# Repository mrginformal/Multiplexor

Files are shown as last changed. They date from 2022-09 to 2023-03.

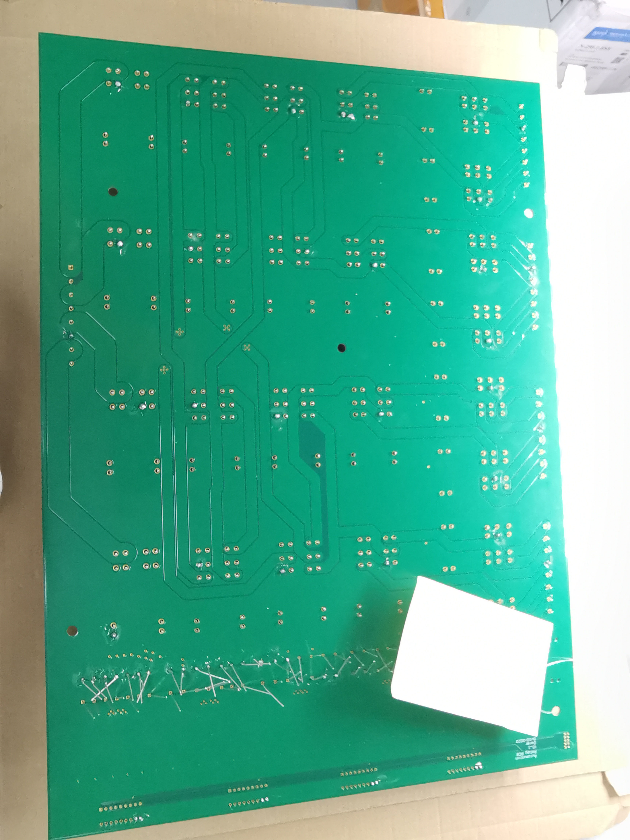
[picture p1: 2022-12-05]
Images/6.jpg

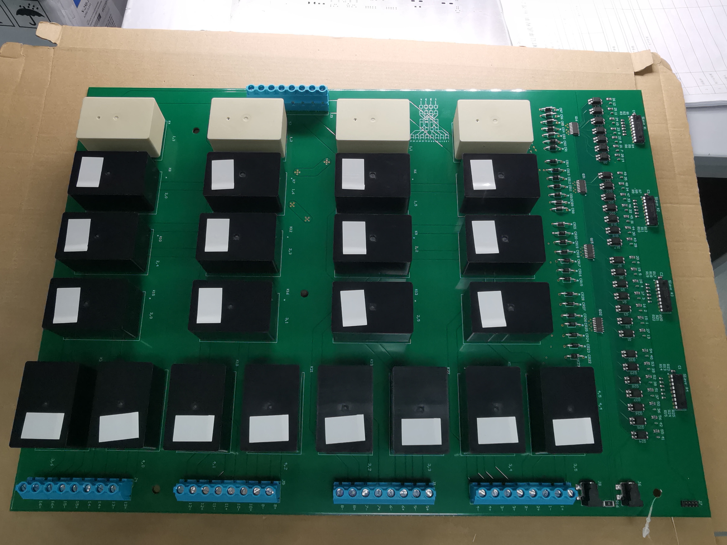
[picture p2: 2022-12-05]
Images/1.jpg

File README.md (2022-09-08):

# 4-IN 16-OUT Multiplexor

This repo contains datasheets, E-CAD and and the Controlling software of the Multiplexor device

The need:

In order for a devices to be tested against multiple use case devices and or lab instruments with out intervention in a single test setup, it is nessisary to have a way to replace the manual process of making the physical connections between the devices. By removing this step, much larger test sequences can be made by chaining together smaller sequences that would otherwise be seperated by manual connection changes. This devices serves to remove or greatly reduce the necessity of reconfiguration. This device is designed to be modular and be used in conjuction with other devices being developed. 

ex: Imagine 16 DC use case devices, connected to 4 yetis simultaneously which are toggled X number of times. Total connections = (#of yetis) X (# of devices) X (# of repeats). If X were 30 for statistical signifigance - that would be 1920 connections a technicial would have to make for just those 16 use cases devices. We currently have over 100 use case devices that are tested each regression. 

Description: 

This device is created such that 8 inputs can be directed to any of the 32 output lines and for the most part run simultaniously with some exceptions. Sets of DPDT relays make the connections and move the paths in pairs(either + - or Hot Neutral) effectively making the device 4 input pairs to any 16 output pairs. It is also worth noting that the terms input and output are loosly defined here and there is no reason one could not use the 16 outputs as inputs and vice versa. The device is rated up to 400V before its creepage requirments are invalidated(AC or DC)and up to 30A of Current. The necissary condition to ensure that the 4 inputs can be connected to the 16 outputs simultaniously is that the electrical paths for each input, output pair must not share a common bus at any point or in other words "cross". To see if paths "cross" refer to the control diagram in firware which shows how the relays create the paths. Typically it is possible for all inputs to be connected to the desired outputs at once and there is an internal check that will terminate the command before execution if a "cross" is detected.

An I2C bus connects to 4 slave devices which each have gpio pins. These pins are used to control the state of each relay. The identifier of the relay on the board and the path diagram is labeled as follows(controlling slave #, bit position of gpio register that controls it). The i2c address is adjustable via address select resistors with up to 8 unique  on each bus. The control software is in python and has preconfigured functions which simply allow the user to state which input --> output connects should be made as well as the duration the connection should last. The nessisary steps to disconnect the live signals, make the path changes, check for short circuits, and over all ensure the isolated pathways are delt with correctly is all handled automatically.

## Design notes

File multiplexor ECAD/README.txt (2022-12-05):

12/01/2022 -- A EMI issue was found where ESD on a nearby conductor could produce an EMI wave that would pull the reset pin on each i2c to GPIO low enough to
trigger Reset. To combate this a .1uf cap was added to each each reset pin to short high frequency signals(200khz was the emi packet)to ground.
A simple 1k resistor was also added between reset and the pi's ground to then bleed off those caps when no power is connected. Additionally the
the supply voltage has been bumped up to 5V from 3.3V. This appears to have fixed the issue.

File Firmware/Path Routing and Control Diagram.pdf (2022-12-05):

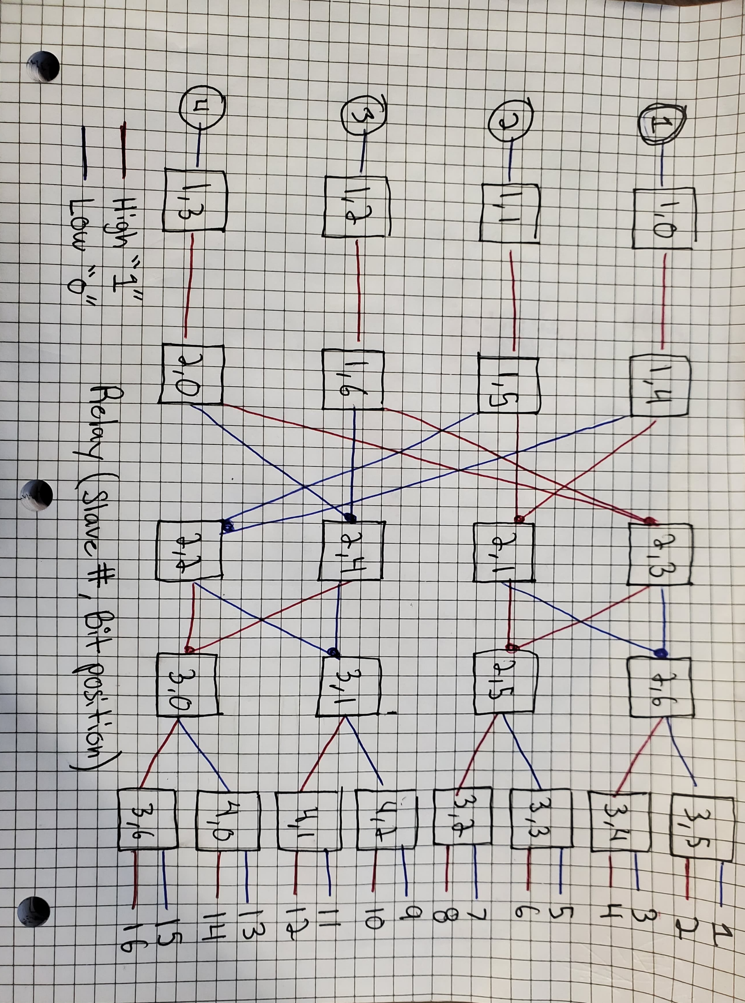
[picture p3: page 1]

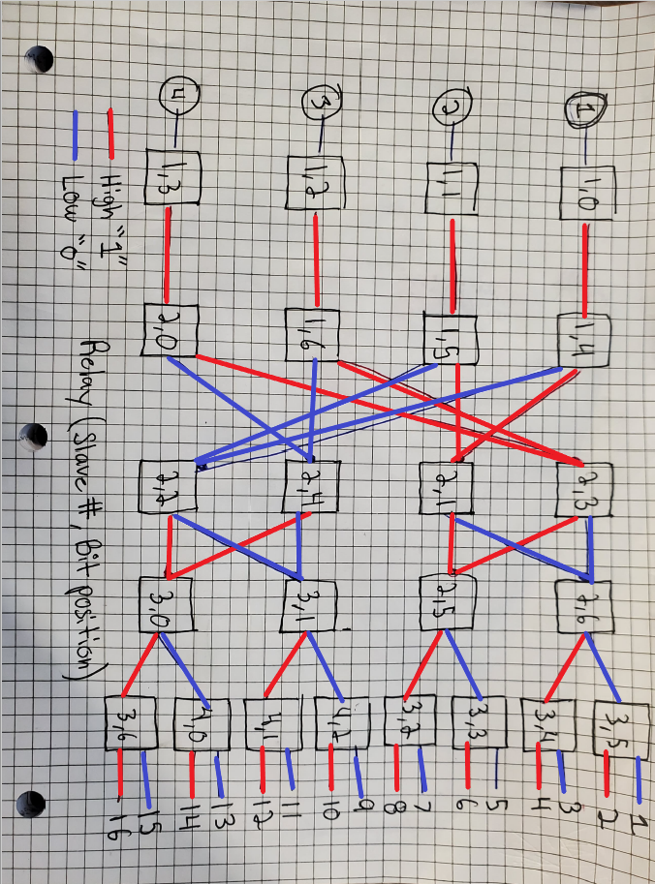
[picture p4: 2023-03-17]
Firmware/tempsnip.png

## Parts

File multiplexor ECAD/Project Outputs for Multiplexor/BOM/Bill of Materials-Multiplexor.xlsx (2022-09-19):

Comment | Description | Designator | Footprint | LibRef | Quantity | Manufacturer | Manufacturer 1
CL10A106MQ8NNNC | No Description Available | 1, 2, 3, 4, 5, 6, 7, 8, 9, 10, 11, 12, 13, 14, 29, 30, 31, 32, 33, 34, 35, 36, 37, 38, 39, 40, 41, 42 | CAP_CL10_SAM | CL10A106MQ8NNNC | 28
RMCF1206FT330R | No Description Available | 15, 16, 17, 18, 19, 20, 21, 22, 23, 24, 25, 26, 27, 28, 43, 44, 45, 46, 47, 48, 49, 50, 51, 52, 53, 54, 55, 56 | STA_RMCF1206_STP | RMCF1206FT330R | 28
GCM188R71H104KA57D | Cap 100nF, 50V, X7R, Ceramic, 1608(0603) | C1, C2, C3, C4 | CAPC1608N_NP | CAP_n100n_0603_50V | 4 | Murata Electronics North America
1N4007-G | No Description Available | CR1, CR2, CR3, CR4, CR5, CR6, CR7, CR8, CR9, CR10, CR11, CR12, CR13, CR14, CR15, CR16, CR17, CR18, CR19, CR20, CR21, CR22, CR23, CR24, CR25, CR26, CR27, CR28 | 1N4-G | 1N4007-G | 28
TB005-762-08BE |  | J1, J2, J3, J4, J5 | CUI_TB005-762-08BE | TB005-762-08BE | 5
PJ-002AH-SMT | 2.1mm x 5.5mm Barrel Jack 5A@24V 30mOhm Contact Resistance | J6, J8 | PJ-002AH-SMT | PJ-002AH-SMT | 2 | CUI Inc
 |  | J7 | 10pinheader | TMMH-105-01-F-D | 1
6-1423008-7 | General Purpose Relay DPST-NO (2 Form A) 24VDC Coil Through Hole | K1, K2, K3, K4 | RELAY_6-1423008-7 | 6-1423008-7 | 4
T92S11D12-24 | No Description Available | K5, K6, K7, K8, K9, K10, K11, K12, K13, K14, K15, K16, K17, K18, K19, K20, K21, K22, K23, K24 | T92S11D12-24_TEC-corrected | T92S11D12-24 | 20
FOD817DSD | OPTOISOLATOR 5KV TRANSISTOR 4SMD | Q1, Q2, Q3, Q4, Q5, Q6, Q7, Q8, Q9, Q10, Q11, Q12, Q13, Q14, Q17, Q18, Q19, Q20, Q21, Q22, Q23, Q24, Q25, Q26, Q27, Q28, Q29, Q30 | FP-709AH-MFG | CMP-2000-06281-2 | 28 | ON Semiconductor
MC1413BDR2G | No Description Available | Q15, Q16, Q31, Q32 | SOIC16_751B-05_ONS | MC1413BDR2G | 4
0603_k4.7K | RES 4.7K OHM 1/10W 1% 0603 SMD | R1, R2, R3, R4, R5, R6, R7, R8, R9, R10, R11, R12, R13, R14, R15, R17, R18, R19, R20, R21, R22, R23, R24, R25 | RESC1608N | 0603_k4.7K | 24 | Vishay Dale
CR2512-J/-000ELF | No Description Available | R16 | BO_CR2512 | CR2512-J/-000ELF | 1
MCP23008-E/P | No Description Available | Slave #1, Slave #2, Slave #3, Slave #4 | PDIP18_300MC_MCH | MCP23008-E/P | 4

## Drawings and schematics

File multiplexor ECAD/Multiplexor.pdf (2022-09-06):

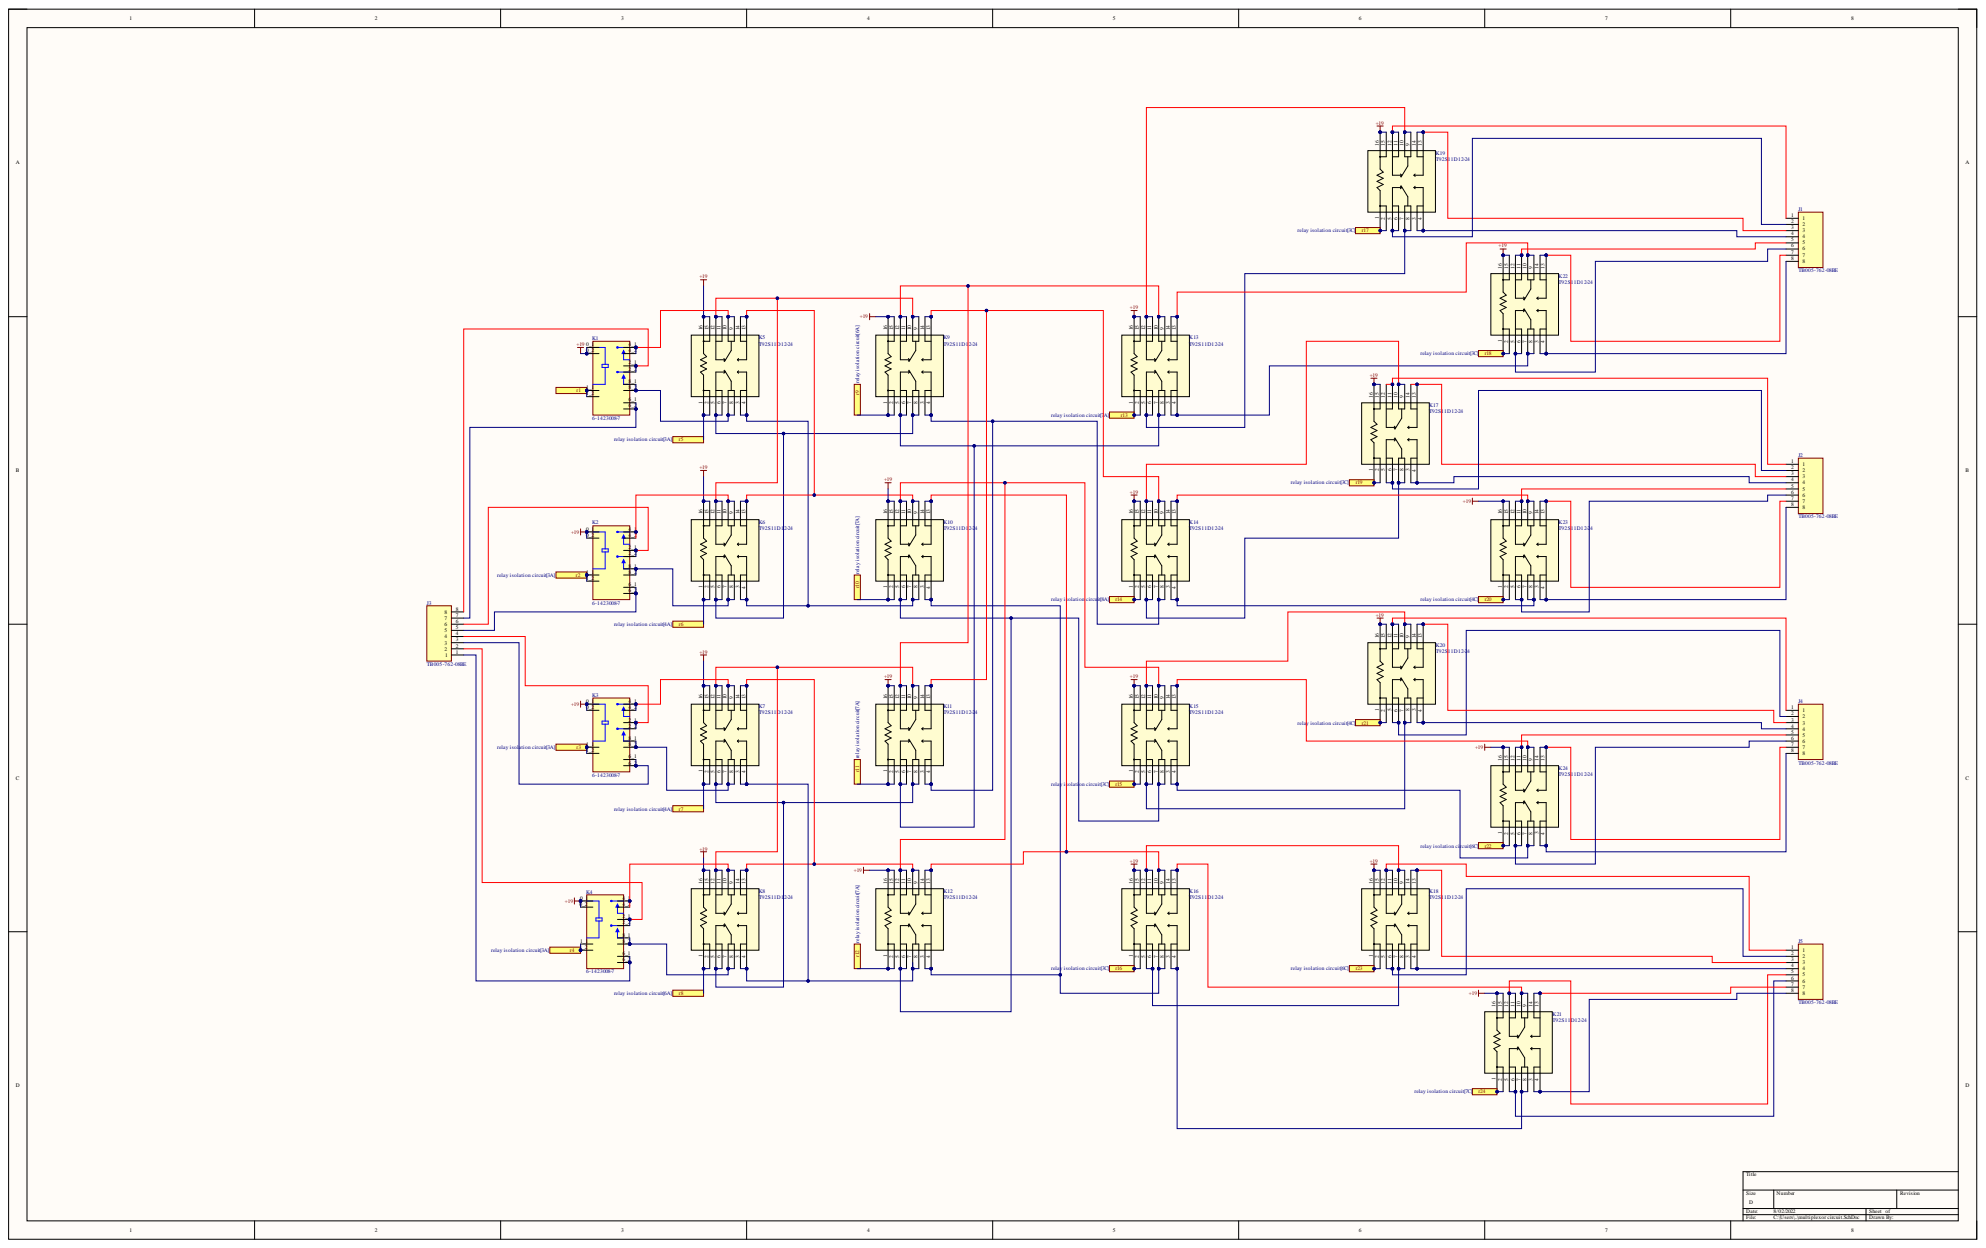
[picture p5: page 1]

r9 relay isolation circuit[6A] r10 relay isolation circuit[7A] r11 relay isolation circuit[7A] r12 relay isolation circuit[7A]

Size DDat | N umb er | Rev i s ion

e: 8 / 0 2 /2022 Fi l e: C: \U sers \ . . \mu l t i p lex or circu i t .SchD oc | Sheet o f Draw n By :

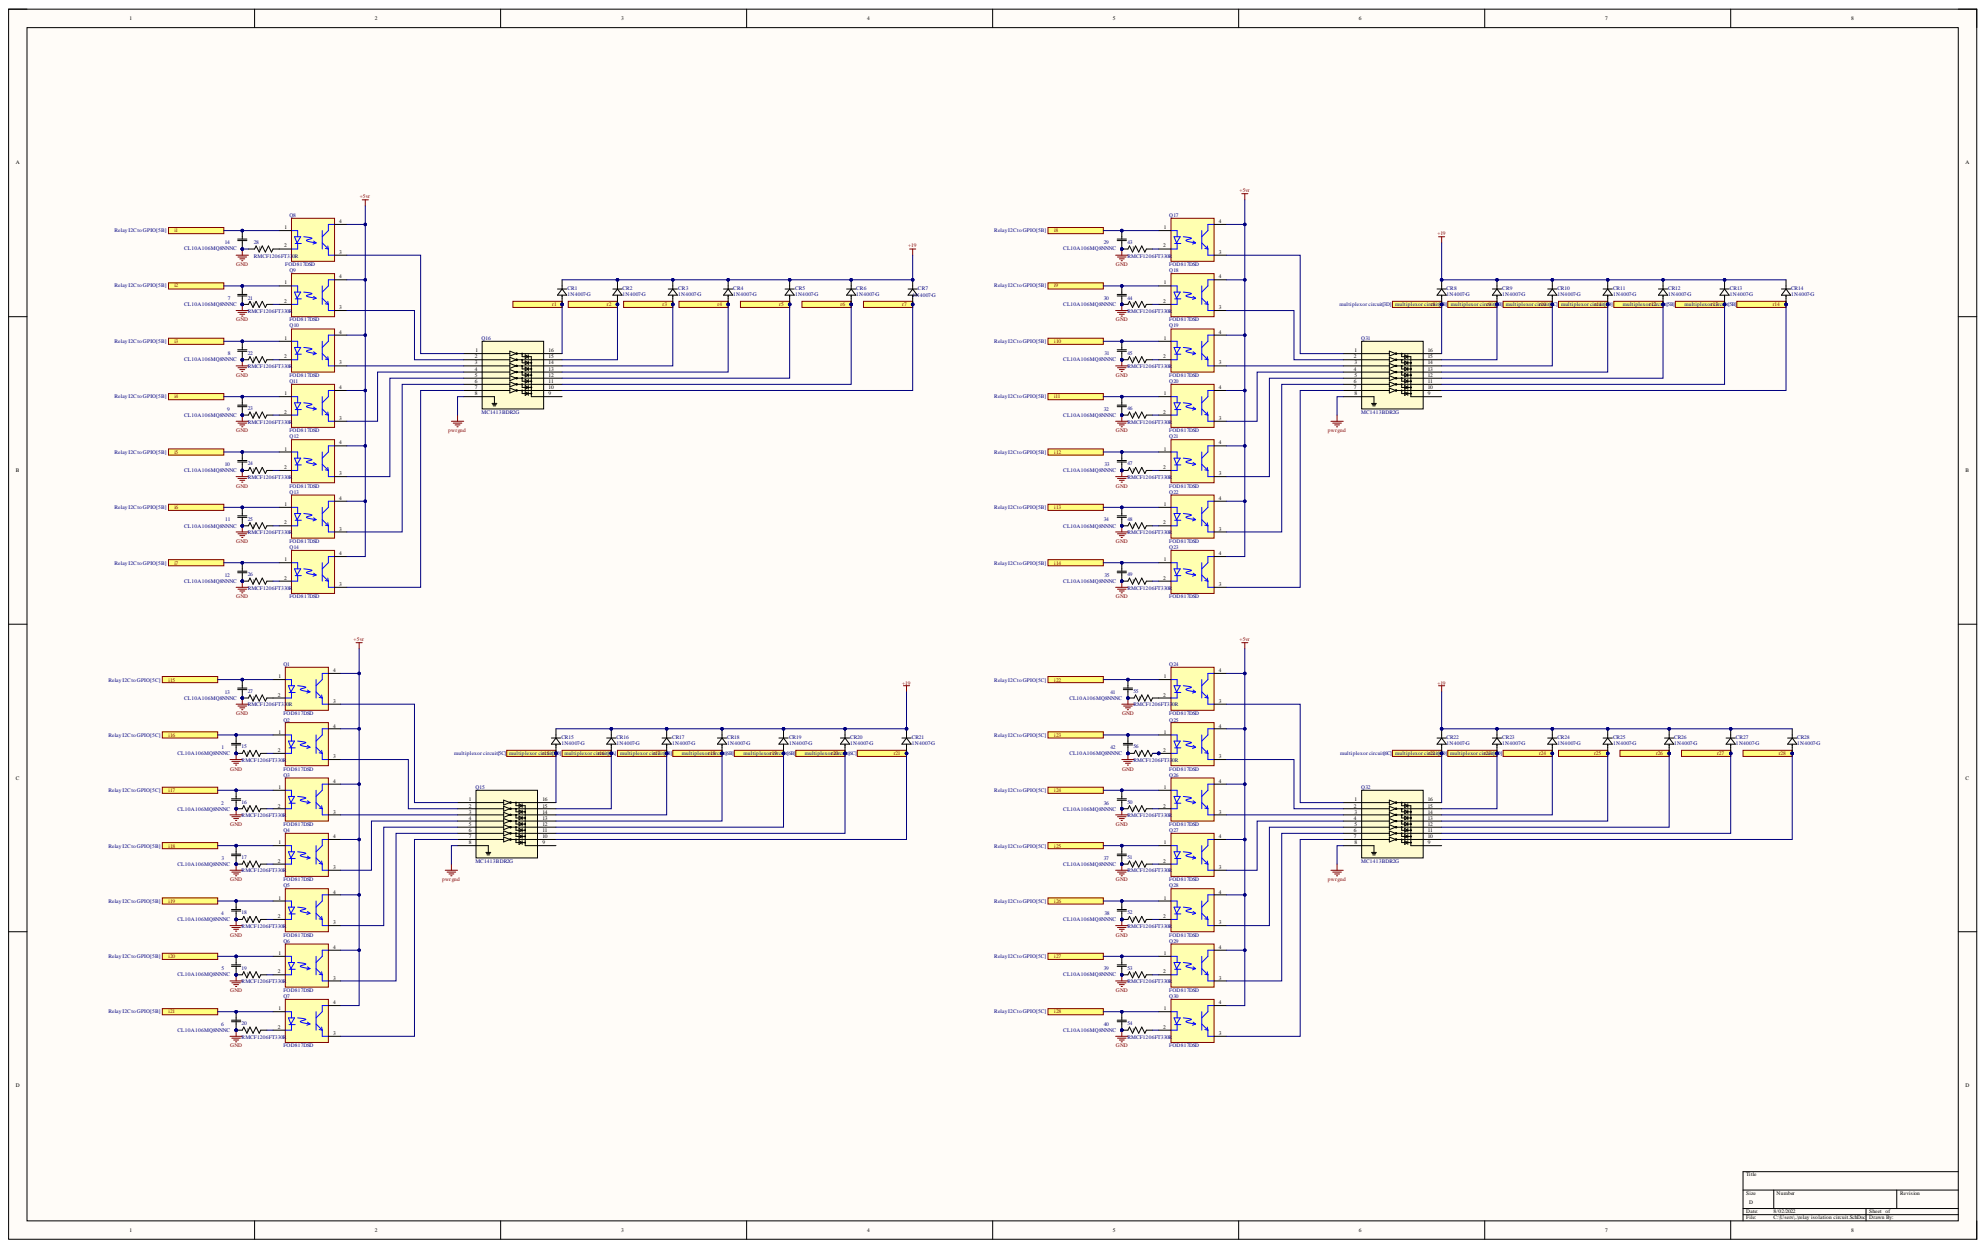
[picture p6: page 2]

3 4

Size D | Number | Revision

Date: 8/02/2022 File: C:\Users\..\relay isolation circuit.SchDoc | Sheet of Drawn By:

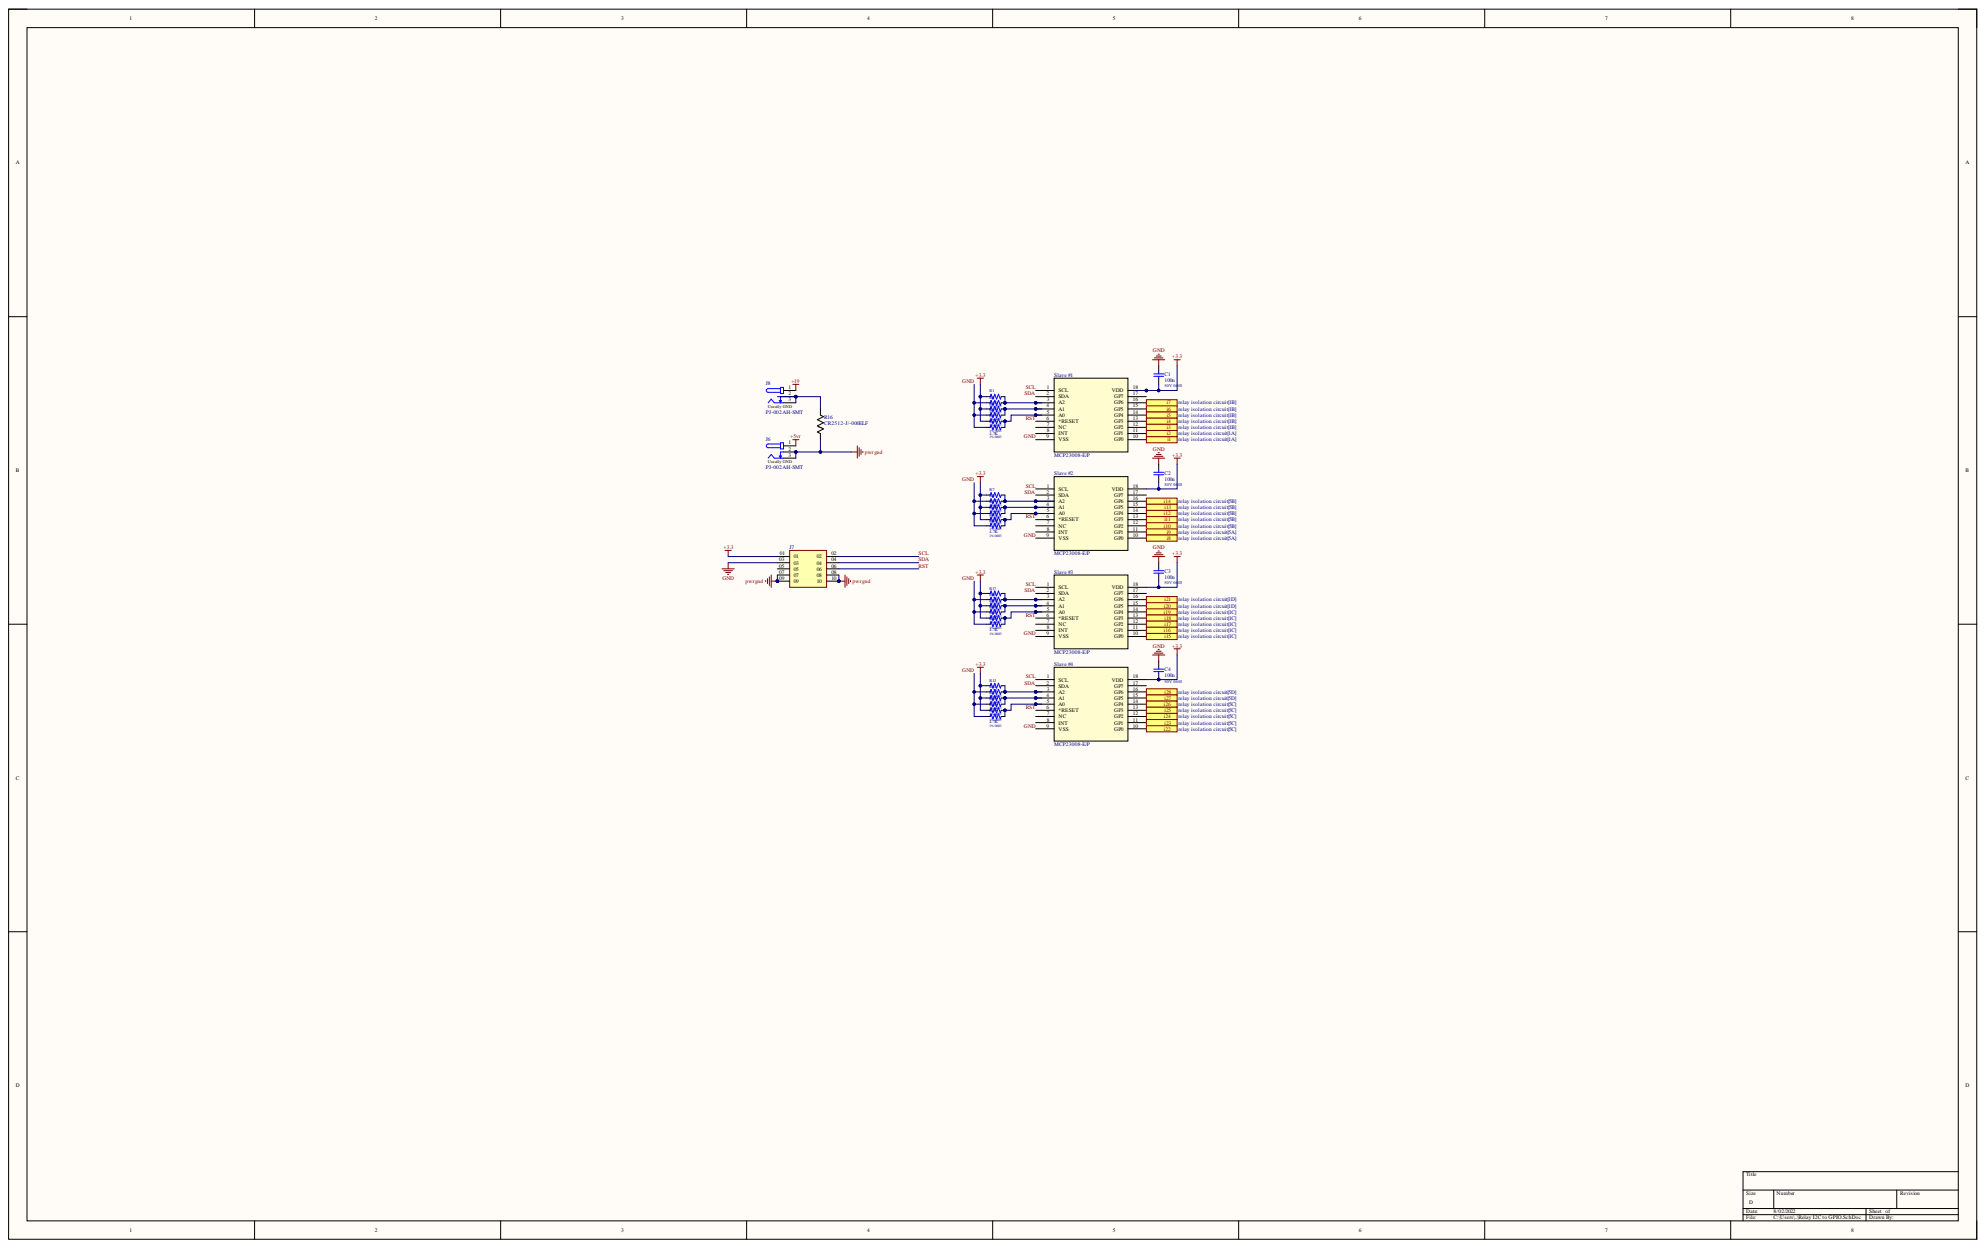
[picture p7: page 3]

Size DDat | N umb er | Rev i s ion

e: 8 / 0 2 /2022 Fi l e: C: \U sers \ . . \Relay I2C t o GPIO .Sch D o c | Sheet o f Draw n By :

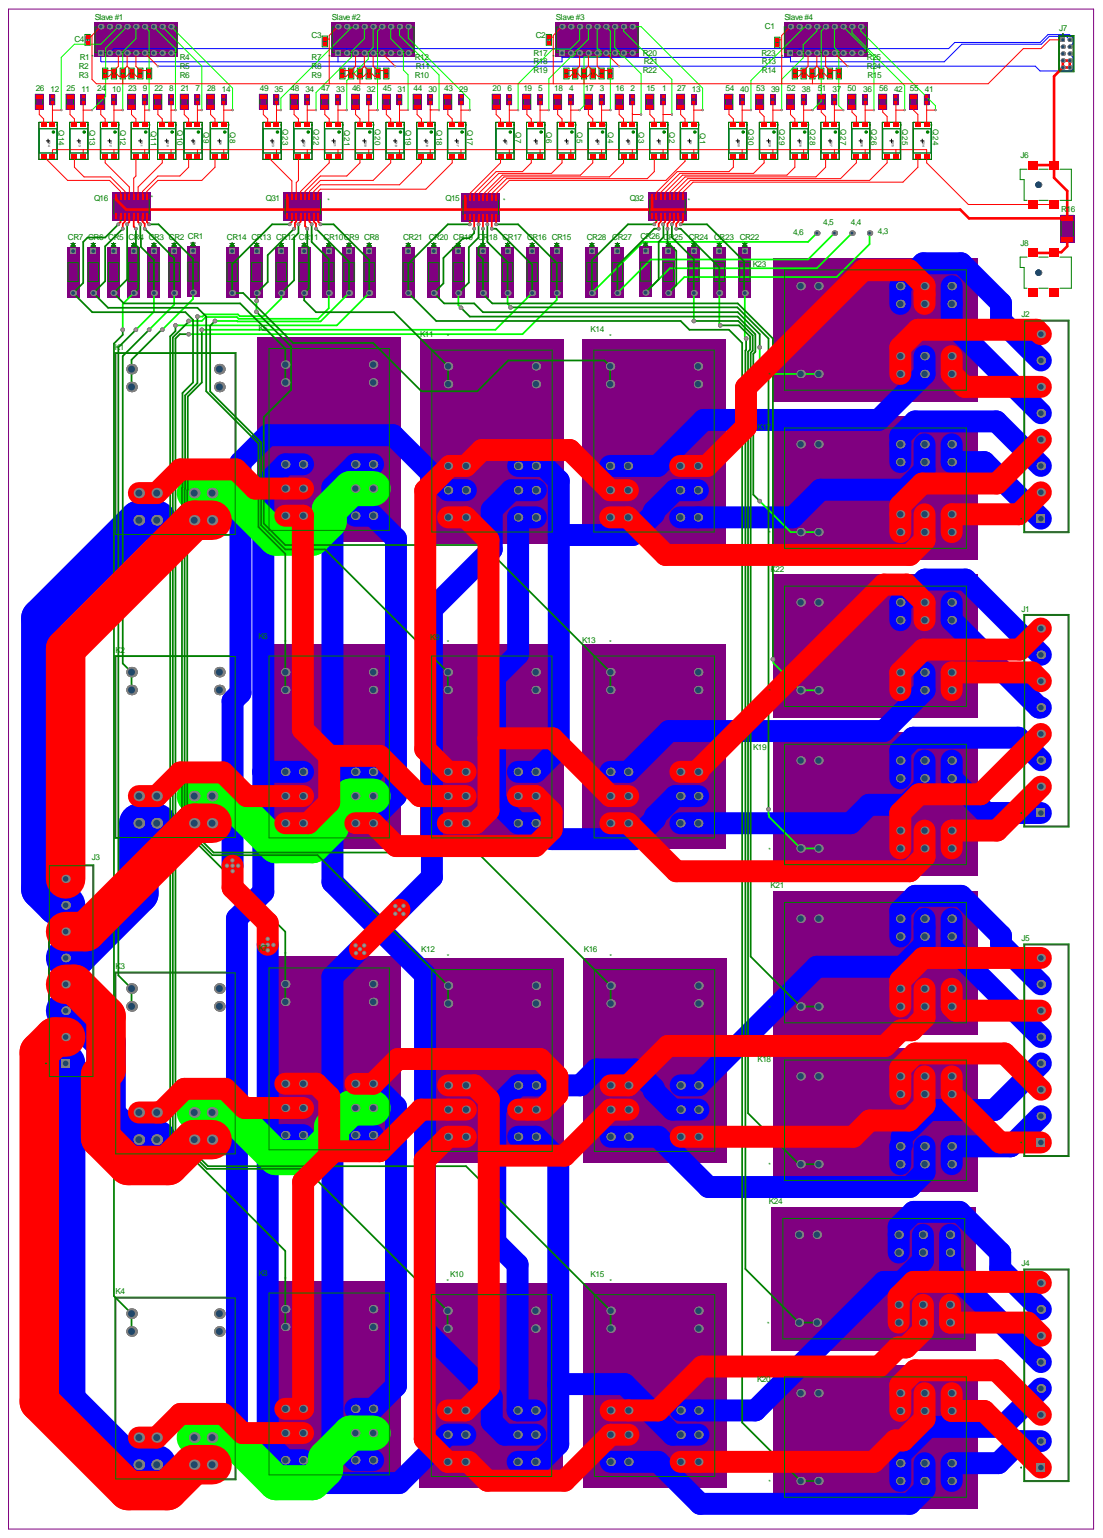
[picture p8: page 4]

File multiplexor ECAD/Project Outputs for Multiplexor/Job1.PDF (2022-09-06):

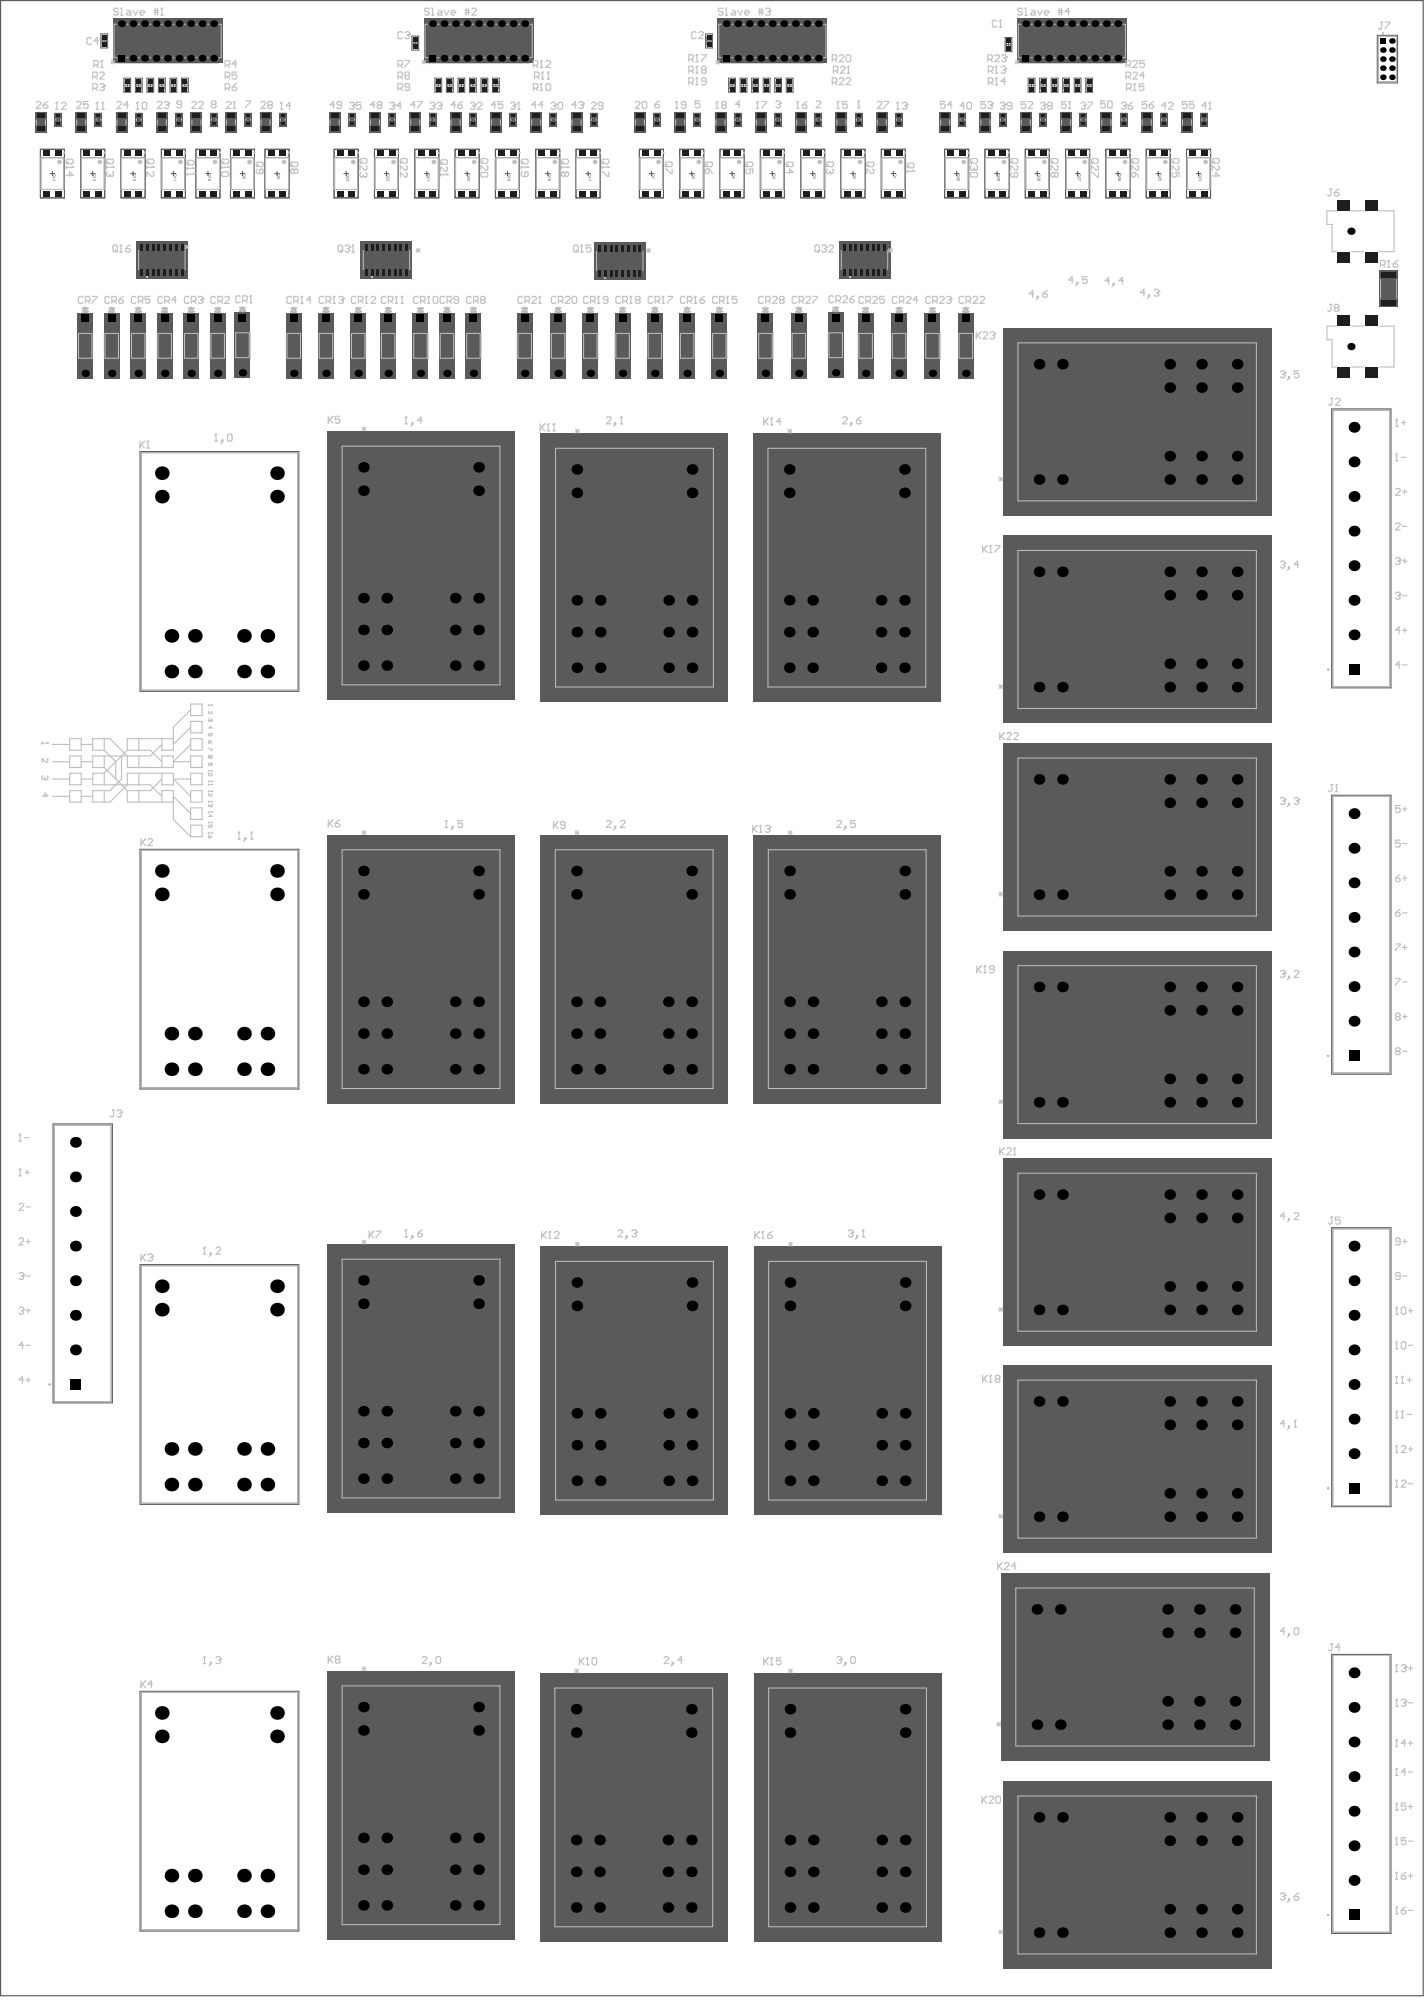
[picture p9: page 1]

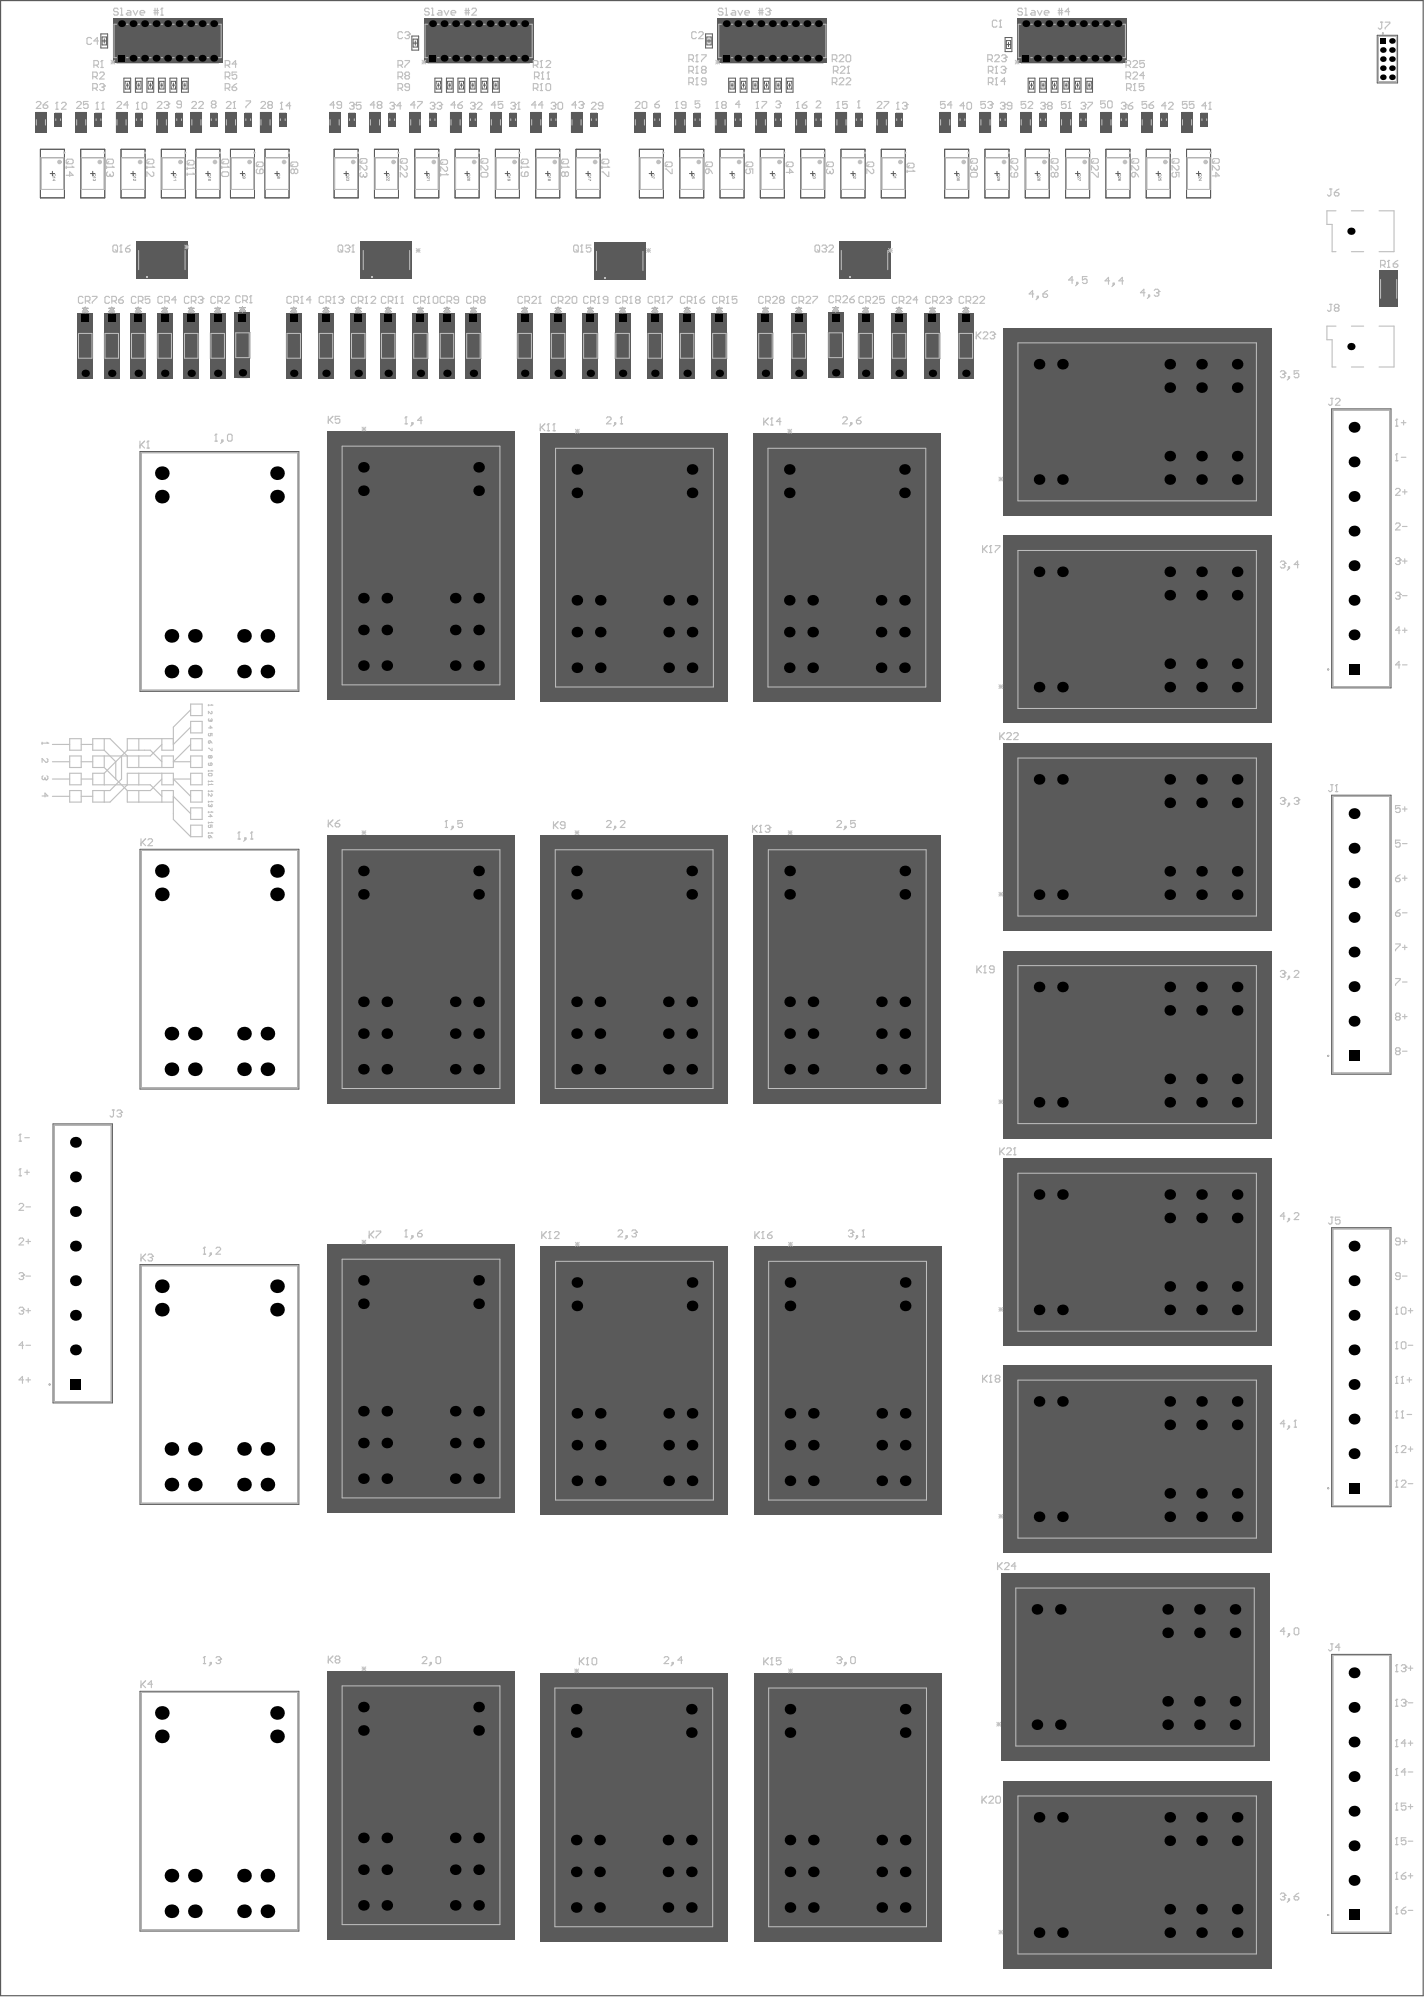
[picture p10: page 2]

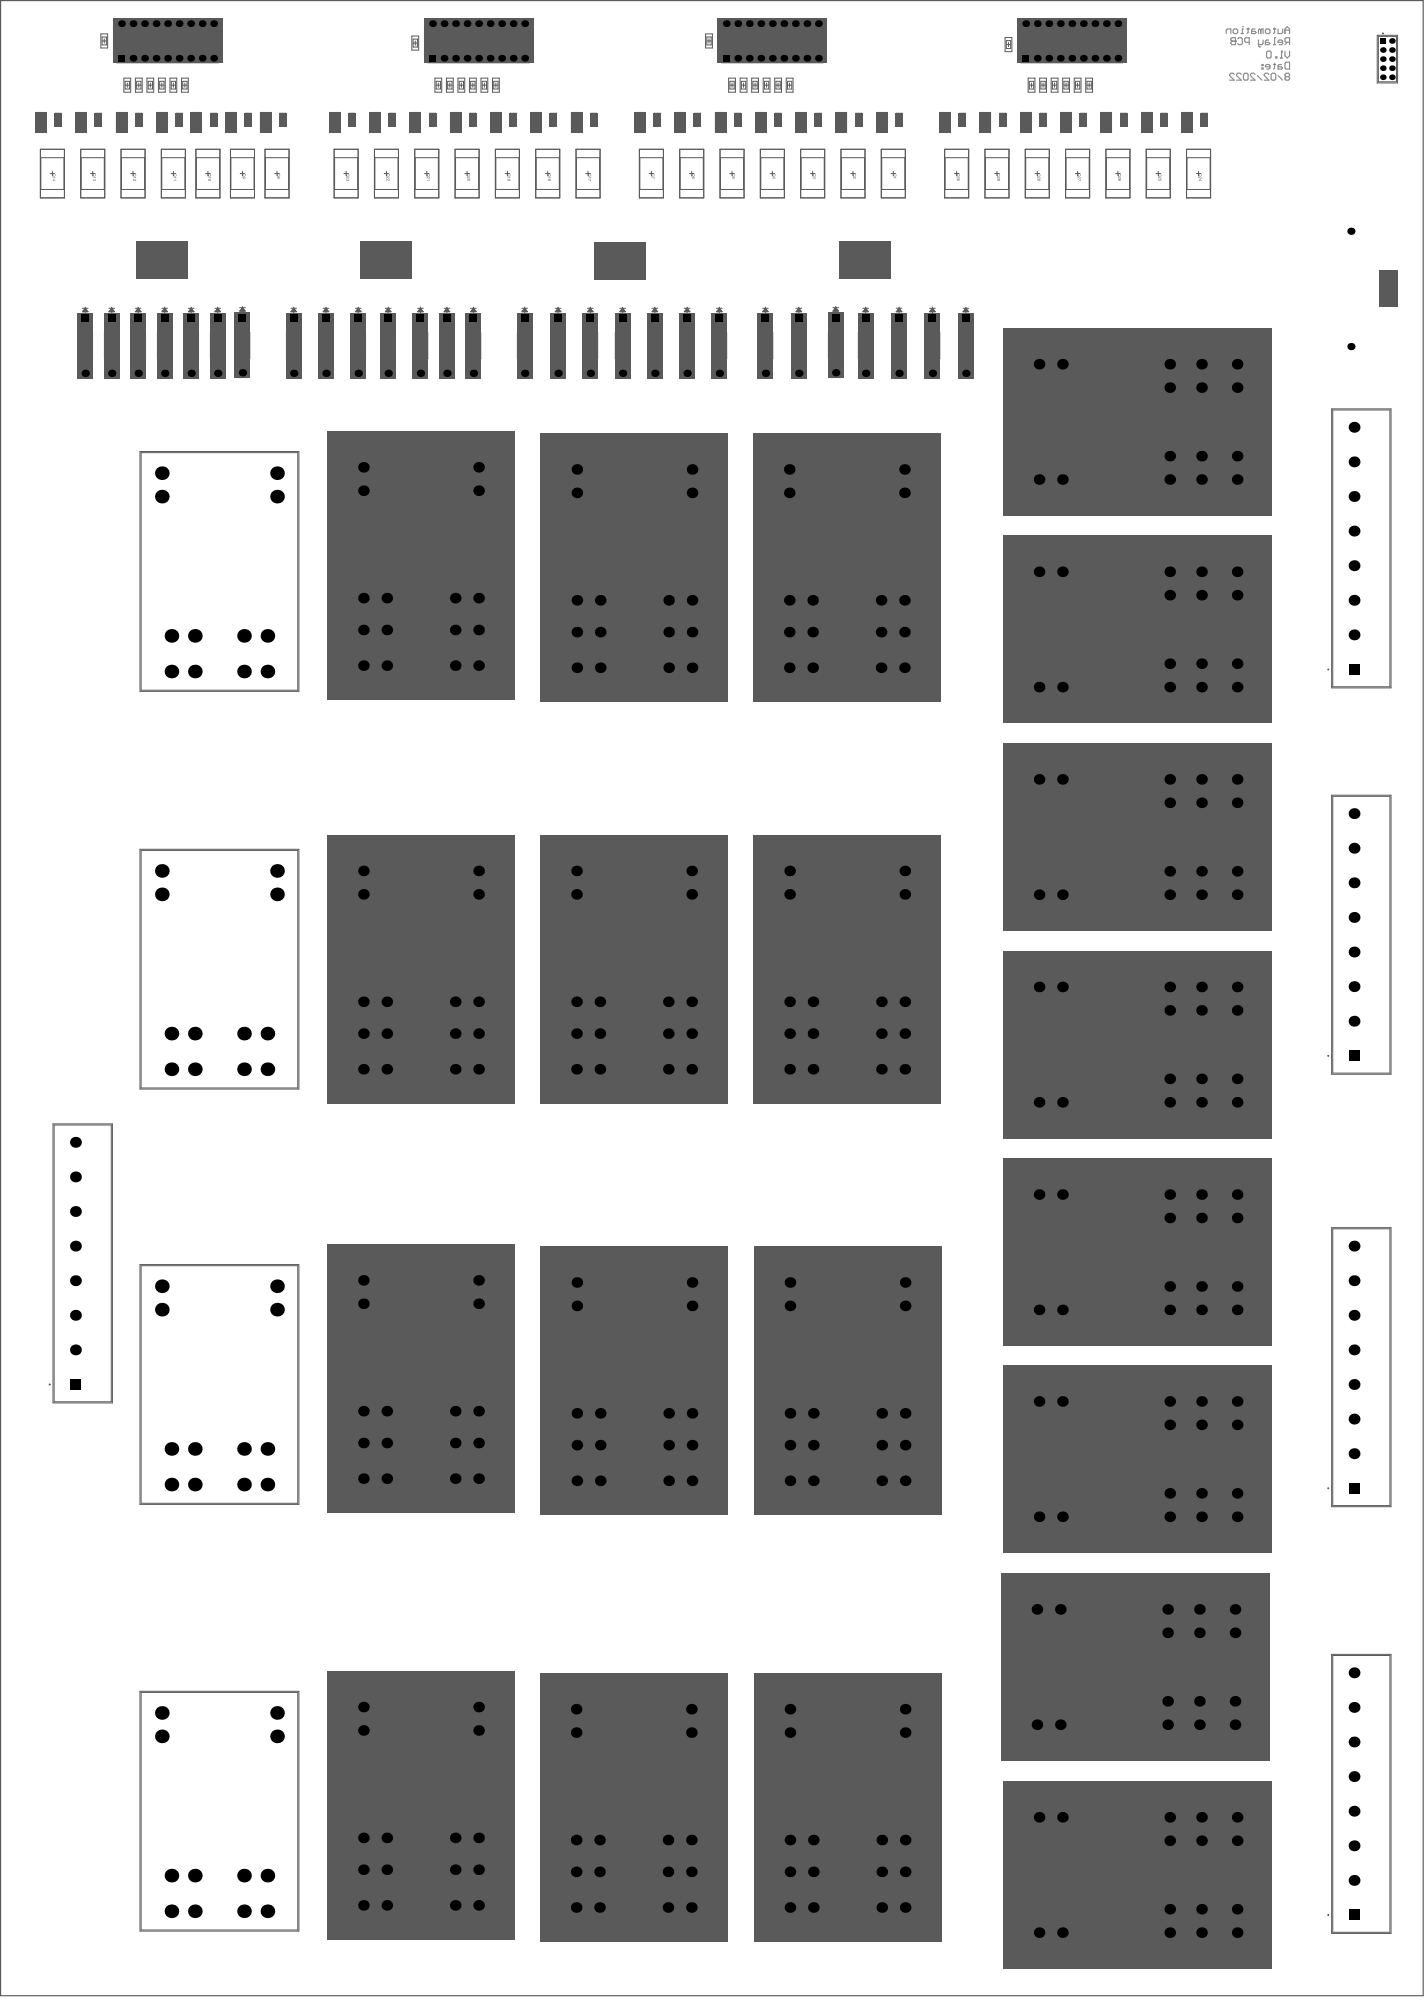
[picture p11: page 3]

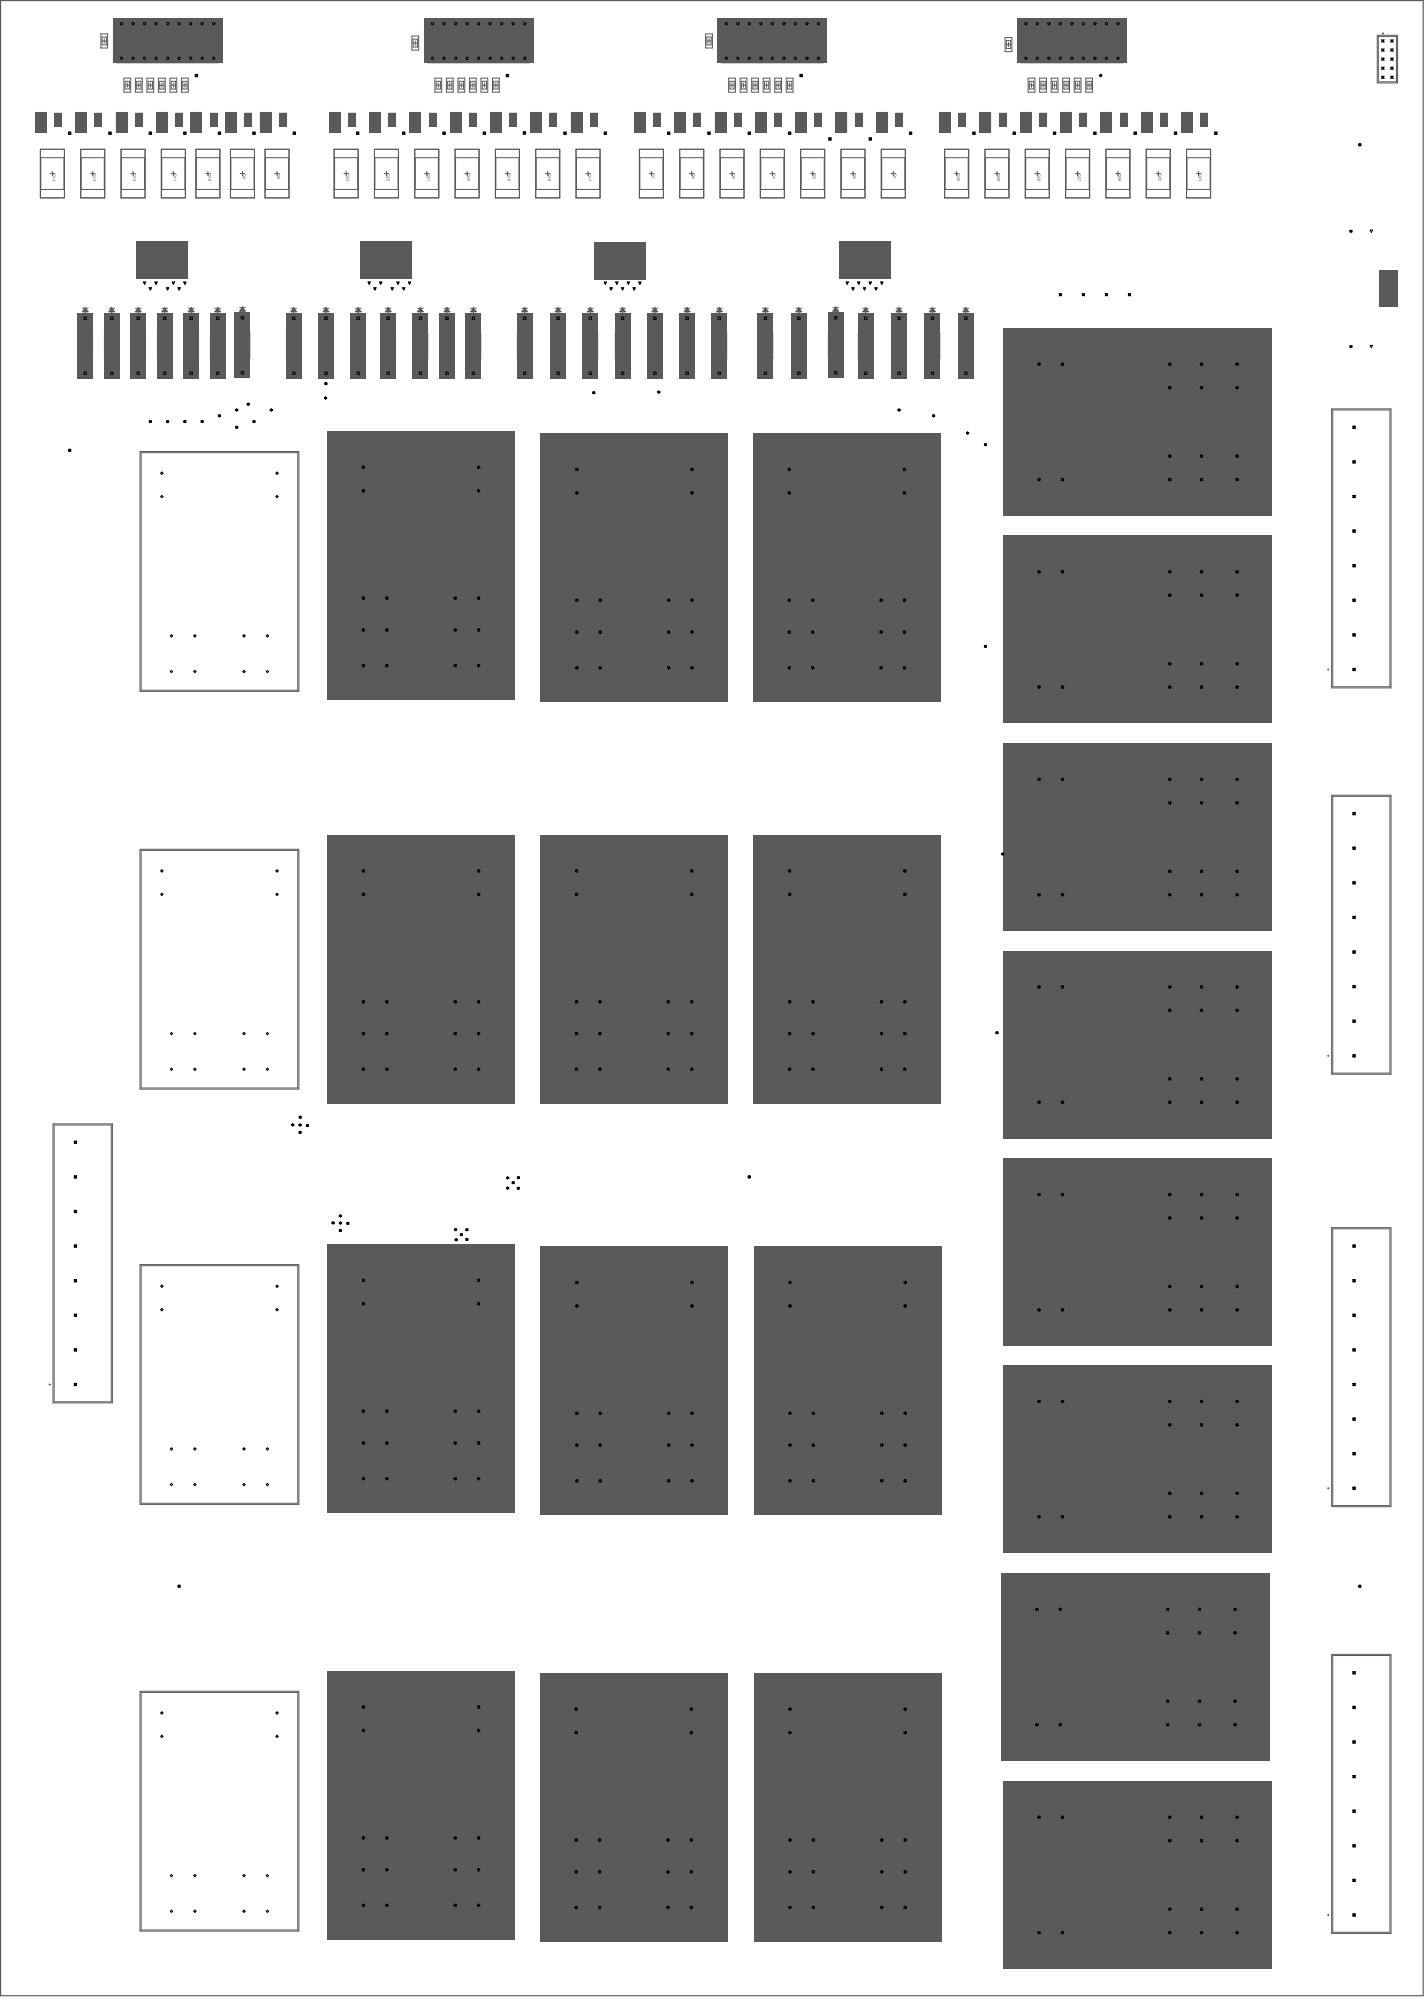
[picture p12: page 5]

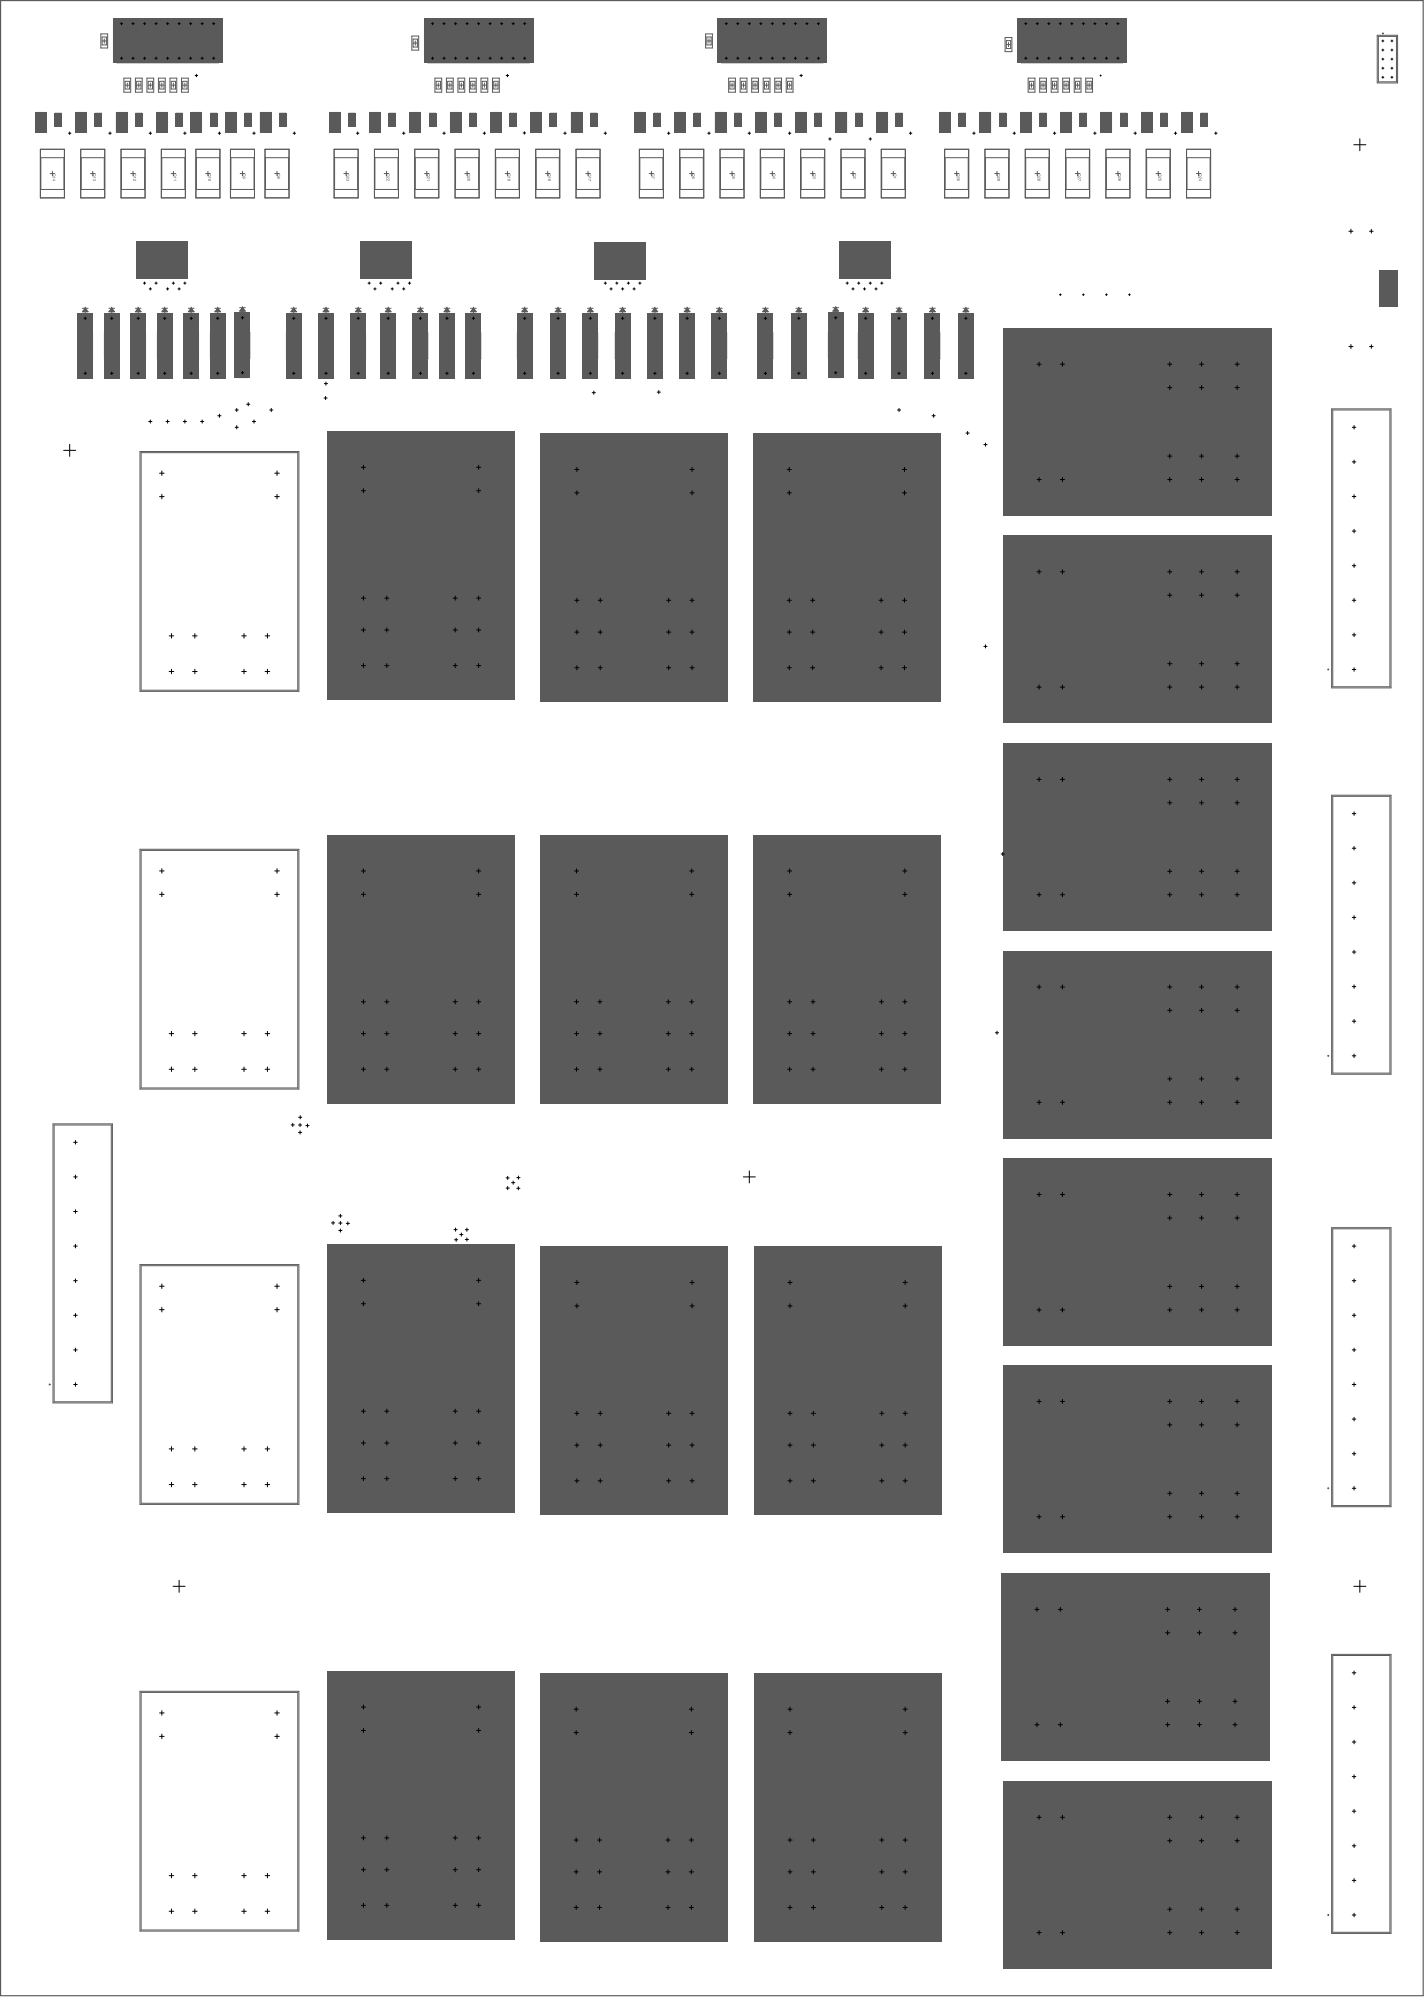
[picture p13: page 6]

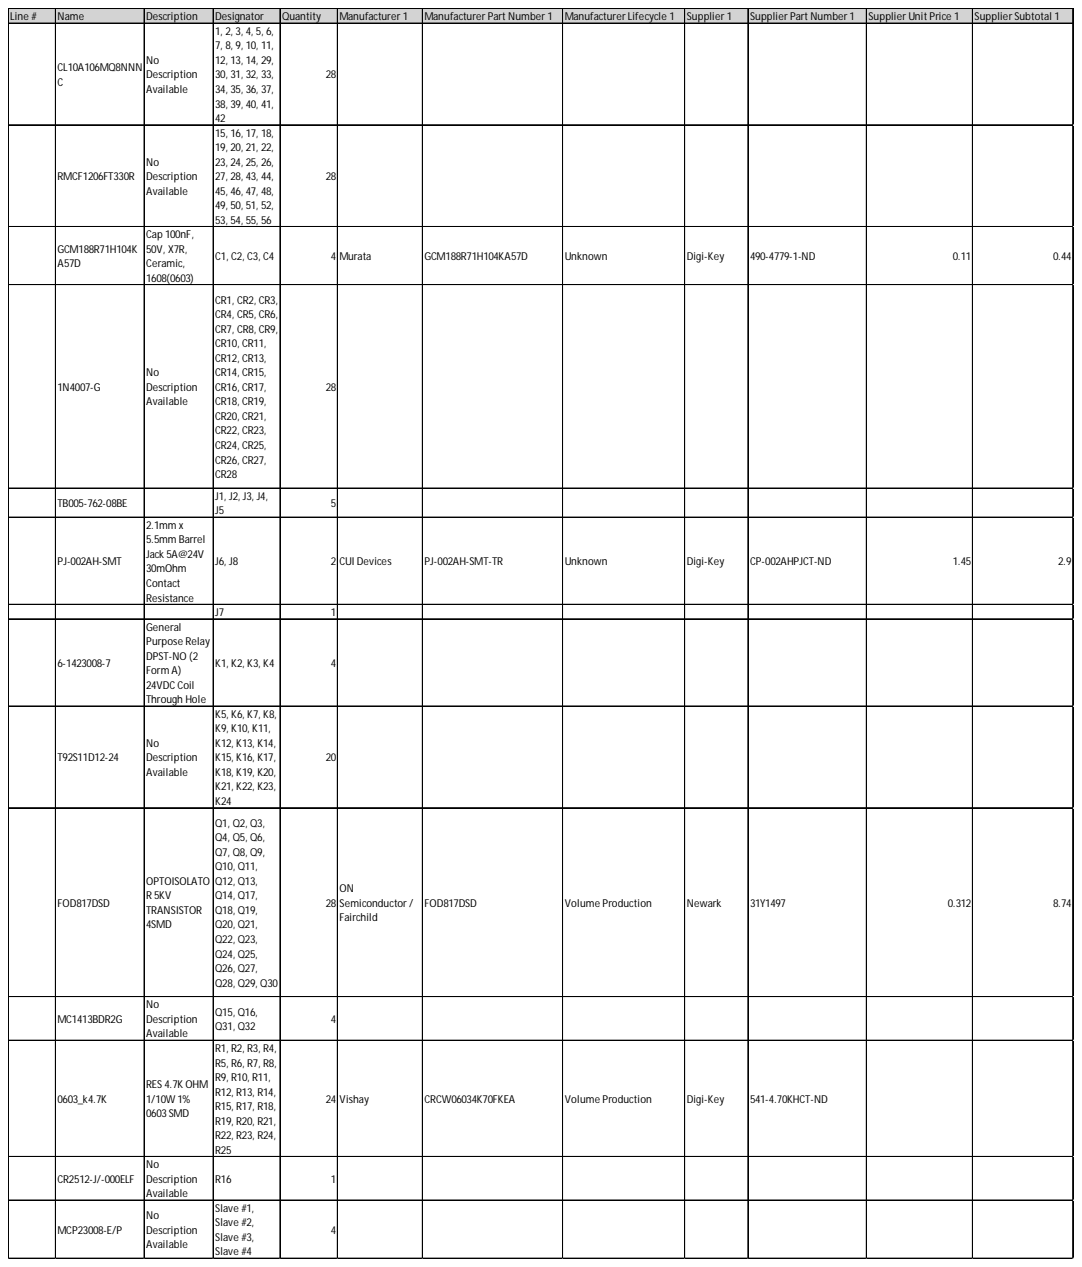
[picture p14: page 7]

Line # | Name | Description | Designator | Quantity | Manufacturer 1 | Manufacturer Part Number 1 | Manufacturer Lifecycle 1 | Supplier 1 | Supplier Part Number 1 | Supplier Unit Price 1 | Supplier Subtotal 1

CL10A106MQ8NNN C | No Description Available | 1, 2, 3, 4, 5, 6, 7, 8, 9, 10, 11, 12, 13, 14, 29, 30, 31, 32, 33, 34, 35, 36, 37, 38, 39, 40, 41, 42 | 28

RMCF1206FT330R | No Description Available | 15, 16, 17, 18, 19, 20, 21, 22, 23, 24, 25, 26, 27, 28, 43, 44, 45, 46, 47, 48, 49, 50, 51, 52, 53, 54, 55, 56 | 28

GCM188R71H104K A57D | Cap 100nF, 50V, X7R, Ceramic, 1608(0603) | C1, C2, C3, C4 | 4 Murata | | GCM188R71H104KA57D | Unknown | Digi-Key | 490-4779-1-ND | 0.11 | 0.44

1N4007-G | No Description Available | CR1, CR2, CR3, CR4, CR5, CR6, CR7, CR8, CR9, CR10, CR11, CR12, CR13, CR14, CR15, CR16, CR17, CR18, CR19, CR20, CR21, CR22, CR23, CR24, CR25, CR26, CR27, CR28 | 28

PJ-002AH-SMT | 2.1mm x 5.5mm Barrel Jack 5A@24V 30mOhm Contact Resistance | J6, J8 | 2 CUI Devices | | PJ-002AH-SMT-TR | Unknown | Digi-Key | CP-002AHPJCT-ND | 1.45 | 2.9

6-1423008-7 | General Purpose Relay DPST-NO (2 Form A) 24VDC Coil Through Hole | K1, K2, K3, K4 | 4

T92S11D12-24 | No Description Available | K5, K6, K7, K8, K9, K10, K11, K12, K13, K14, K15, K16, K17, K18, K19, K20, K21, K22, K23, K24 | 20

FOD817DSD | OPTOISOLATO R 5KV TRANSISTOR 4SMD | Q1, Q2, Q3, Q4, Q5, Q6, Q7, Q8, Q9, Q10, Q11, Q12, Q13, Q14, Q17, Q18, Q19, Q20, Q21, Q22, Q23, Q24, Q25, Q26, Q27, Q28, Q29, Q30 | 28 | ON Semiconductor / Fairchild | FOD817DSD | Volume Production | Newark | 31Y1497 | 0.312 | 8.74

MC1413BDR2G | No Description Available | Q15, Q16, Q31, Q32 | 4

0603_k4.7K | RES 4.7K OHM 1/10W 1% 0603 SMD | R1, R2, R3, R4, R5, R6, R7, R8, R9, R10, R11, R12, R13, R14, R15, R17, R18, R19, R20, R21, R22, R23, R24, R25 | 24 Vishay | | CRCW06034K70FKEA | Volume Production | Digi-Key | 541-4.70KHCT-ND

CR2512-J/-000ELF | No Description Available | R16 | 1

MCP23008-E/P | No Description Available | Slave #1, Slave #2, Slave #3, Slave #4 | 4

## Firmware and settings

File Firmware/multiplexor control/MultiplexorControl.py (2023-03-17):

import numpy as np
import time
import threading
import RPi.GPIO
from smbus2 import SMBus  
from pathdict import pathdata


class Multi_board:
    def __init__(self):
        self.registers = {  
            'IODIR' : 0x00,
            'IPOL' : 0x01,
            'GPINTEN' : 0x02,
            'DEFVAL' : 0x03,
            'INTCON' : 0x04,
            'IOCON' : 0x05,
            'GPPU' : 0x06,
            'INTF' : 0x07,
            'INTCAP' : 0x08,
            'GPIO' : 0x09,
            'OLAT' : 0x0A 
        }
        self.slv_addresses = {  #default, but may need to be overwritten for diffrent boards as it is hardware addressed.
            0 : 0x21,
            1 : 0x22,
            2 : 0x23,
            3 : 0x24 
        }
        self.bus = SMBus(1)

    def reg_data(self, pth_s):
    # This fuction builds the register data in the form of a matrix, it builds both a on and off state (same connects with exception of the first colum of relays)
    # Each row is the register of a diffrent slave, slave one being row one and so on. There is also a is active matrix which tracks if the relay have a signal
    # being sent through it, if two paths try to set a rela y to active(writing a 1 to the matrix) that indicates the paths would share a bus, cuasing a short circuit.
    # Note: already active pertains to one already used within the same command. not previous commands or states.

        reg_packet = np.zeros([4,8], dtype = int)
        active_pth = np.zeros([4,8], dtype = int)

        for path in pth_s:
            for relay in pathdata[path]:
                reg_packet[relay[0] - 1][relay[1]] = relay[2]       # writes the 1's and zero's based on data from pathdict file

                if active_pth[relay[0] - 1][relay[1]] == 1:         # checks if the relay is already used by a path, if so raises value error, otherwise sets it to in use state.
                    raise ValueError('Short Circuit detected from path command {}, select diffrent paths and refer to connection diagram to ensure paths do not cross'.format(str(pth_s)))
                else:
                    active_pth[relay[0] - 1][relay[1]] = 1

        on_regs = reg_packet
        off_regs = np.matrix.copy(on_regs)                            # makes off reg by forcing all double pole single throw relays to off but maintains other connections
        off_regs[0][0:4] = 0

        return (off_regs, on_regs)    

    def compile_reg_data(self, pth_s):
    # This function feeds the data to the reg_data function and then converts it into hex data. 

        cmd_hex = []                    # stores (on_regs, off_regs) in hex form
        for matrix in self.reg_data(pth_s):
            reg_hex = []

            for row in matrix: 
                b = ''                  # technically this does not need to be a string, but i like to see the leading zeros in a 8-bit binary string. 00001000.
                for m in reversed(row): # this reverses the marix binary string as a 0000 0001 in binary is represented as 1000 0000 in the matrix
                    b += str(m)
                c = int(b, 2)
                reg_hex.append(c)       # outputs hex register values in list, (reg1,reg2,reg3,reg4)
            cmd_hex.append(reg_hex)

        return cmd_hex
        
    def wrt_reg_data(self, pth_s,v):          
    # sends the cmd_hex data to the i2c bus and ultimately the slaves, v selects the onstate(1) or offstate(0)

        a = self.compile_reg_data(pth_s)
        c = 0                           # from the cmd_hex nested list.
        for n in a[v]:
            self.bus.write_byte_data(self.slv_addresses[c], self.registers['GPIO'], n)       # uncomment when on pi
            c += 1


    def configure_slaves(self):             
    # sets the slave configurations register on each device.
        print('configuring')
        for i in range(len(self.slv_addresses)):
            self.bus.write_byte_data(self.slv_addresses[i], self.registers['IOCON'], 0x3a)       # uncomment when on pi
            self.bus.write_byte_data(self.slv_addresses[i], self.registers['IODIR'], 0x00)


def main():
    MB = Multi_board()
    MB.configure_slaves()
    time.sleep(1)
    MB.wrt_reg_data(((1,1),(2,9),(3,5),(4,13)),0)
    time.sleep(3)
    MB.wrt_reg_data(((1,1),(2,9),(3,5),(4,13)),1)
    time.sleep(2)
    MB.wrt_reg_data(((1,1),(2,9),(3,5),(4,13)),0)

if __name__ == '__main__':
    main()

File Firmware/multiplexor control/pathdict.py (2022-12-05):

pathdata = {
    (1,1) :  ((1,0,1),(1,4,1),(2,1,0),(2,6,0),(3,5,0)),    
    (1,2) :  ((1,0,1),(1,4,1),(2,1,0),(2,6,0),(3,5,1)),   
    (1,3) :  ((1,0,1),(1,4,1),(2,1,0),(2,6,1),(3,4,0)),   
    (1,4) :  ((1,0,1),(1,4,1),(2,1,0),(2,6,1),(3,4,1)),   
    (1,5) :  ((1,0,1),(1,4,1),(2,1,1),(2,5,0),(3,3,0)),   
    (1,6) :  ((1,0,1),(1,4,1),(2,1,1),(2,5,0),(3,3,1)),   
    (1,7) :  ((1,0,1),(1,4,1),(2,1,1),(2,5,1),(3,2,0)),   
    (1,8) :  ((1,0,1),(1,4,1),(2,1,1),(2,5,1),(3,2,1)),   
    (1,9) :  ((1,0,1),(1,4,0),(2,2,0),(3,1,0),(4,2,0)),      
    (1,10) : ((1,0,1),(1,4,0),(2,2,0),(3,1,0),(4,2,1)),  
    (1,11) : ((1,0,1),(1,4,0),(2,2,0),(3,1,1),(4,1,0)),  
    (1,12) : ((1,0,1),(1,4,0),(2,2,0),(3,1,1),(4,1,1)),  
    (1,13) : ((1,0,1),(1,4,0),(2,2,1),(3,0,0),(4,0,0)),  
    (1,14) : ((1,0,1),(1,4,0),(2,2,1),(3,0,0),(4,0,1)),    
    (1,15) : ((1,0,1),(1,4,0),(2,2,1),(3,0,1),(3,6,0)),  
    (1,16) : ((1,0,1),(1,4,0),(2,2,1),(3,0,1),(3,6,1)),
    
    (2,1) :  ((1,1,1),(1,5,1),(2,1,0),(2,6,0),(3,5,0)),      
    (2,2) :  ((1,1,1),(1,5,1),(2,1,0),(2,6,0),(3,5,1)),      
    (2,3) :  ((1,1,1),(1,5,1),(2,1,0),(2,6,1),(3,4,0)),      
    (2,4) :  ((1,1,1),(1,5,1),(2,1,0),(2,6,1),(3,4,1)),      
    (2,5) :  ((1,1,1),(1,5,1),(2,1,1),(2,5,0),(3,3,0)),      
    (2,6) :  ((1,1,1),(1,5,1),(2,1,1),(2,5,0),(3,3,1)),      
    (2,7) :  ((1,1,1),(1,5,1),(2,1,1),(2,5,1),(3,2,0)),      
    (2,8) :  ((1,1,1),(1,5,1),(2,1,1),(2,5,1),(3,2,1)),
    (2,9) :  ((1,1,1),(1,5,0),(2,2,0),(3,1,0),(4,2,0)),          
    (2,10) : ((1,1,1),(1,5,0),(2,2,0),(3,1,0),(4,2,1)),     
    (2,11) : ((1,1,1),(1,5,0),(2,2,0),(3,1,1),(4,1,0)),     
    (2,12) : ((1,1,1),(1,5,0),(2,2,0),(3,1,1),(4,1,1)),     
    (2,13) : ((1,1,1),(1,5,0),(2,2,1),(3,0,0),(4,0,0)),     
    (2,14) : ((1,1,1),(1,5,0),(2,2,1),(3,0,0),(4,0,1)),     
    (2,15) : ((1,1,1),(1,5,0),(2,2,1),(3,0,1),(3,6,0)),     
    (2,16) : ((1,1,1),(1,5,0),(2,2,1),(3,0,1),(3,6,1)), 

    (3,1) :  ((1,2,1),(1,6,1),(2,3,0),(2,6,0),(3,5,0)),    
    (3,2) :  ((1,2,1),(1,6,1),(2,3,0),(2,6,0),(3,5,1)),   
    (3,3) :  ((1,2,1),(1,6,1),(2,3,0),(2,6,1),(3,4,0)),   
    (3,4) :  ((1,2,1),(1,6,1),(2,3,0),(2,6,1),(3,4,1)),   
    (3,5) :  ((1,2,1),(1,6,1),(2,3,1),(2,5,0),(3,3,0)),   
    (3,6) :  ((1,2,1),(1,6,1),(2,3,1),(2,5,0),(3,3,1)),   
    (3,7) :  ((1,2,1),(1,6,1),(2,3,1),(2,5,1),(3,2,0)),   
    (3,8) :  ((1,2,1),(1,6,1),(2,3,1),(2,5,1),(3,2,1)),   
    (3,9) :  ((1,2,1),(1,6,0),(2,4,0),(3,1,0),(4,2,0)),      
    (3,10) : ((1,2,1),(1,6,0),(2,4,0),(3,1,0),(4,2,1)),  
    (3,11) : ((1,2,1),(1,6,0),(2,4,0),(3,1,1),(4,1,0)),  
    (3,12) : ((1,2,1),(1,6,0),(2,4,0),(3,1,1),(4,1,1)),  
    (3,13) : ((1,2,1),(1,6,0),(2,4,1),(3,0,0),(4,0,0)),  
    (3,14) : ((1,2,1),(1,6,0),(2,4,1),(3,0,0),(4,0,1)),  
    (3,15) : ((1,2,1),(1,6,0),(2,4,1),(3,0,1),(3,6,0)),  
    (3,16) : ((1,2,1),(1,6,0),(2,4,1),(3,0,1),(3,6,1)),

    (4,1) :  ((1,3,1),(2,0,1),(2,3,0),(2,6,0),(3,5,0)),    
    (4,2) :  ((1,3,1),(2,0,1),(2,3,0),(2,6,0),(3,5,1)),   
    (4,3) :  ((1,3,1),(2,0,1),(2,3,0),(2,6,1),(3,4,0)),   
    (4,4) :  ((1,3,1),(2,0,1),(2,3,0),(2,6,1),(3,4,1)),   
    (4,5) :  ((1,3,1),(2,0,1),(2,3,1),(2,5,0),(3,3,0)),   
    (4,6) :  ((1,3,1),(2,0,1),(2,3,1),(2,5,0),(3,3,1)),   
    (4,7) :  ((1,3,1),(2,0,1),(2,3,1),(2,5,1),(3,2,0)),   
    (4,8) :  ((1,3,1),(2,0,1),(2,3,1),(2,5,1),(3,2,1)),   
    (4,9) :  ((1,3,1),(2,0,0),(2,4,0),(3,1,0),(4,2,0)),      
    (4,10) : ((1,3,1),(2,0,0),(2,4,0),(3,1,0),(4,2,1)),  
    (4,11) : ((1,3,1),(2,0,0),(2,4,0),(3,1,1),(4,1,0)),  
    (4,12) : ((1,3,1),(2,0,0),(2,4,0),(3,1,1),(4,1,1)),  
    (4,13) : ((1,3,1),(2,0,0),(2,4,1),(3,0,0),(4,0,0)),  
    (4,14) : ((1,3,1),(2,0,0),(2,4,1),(3,0,0),(4,0,1)),  
    (4,15) : ((1,3,1),(2,0,0),(2,4,1),(3,0,1),(3,6,0)),  
    (4,16) : ((1,3,1),(2,0,0),(2,4,1),(3,0,1),(3,6,1)), 
    
}

'''
this file contains the physical path data from the multiplexor circuit, it tells you the relay high low states
in order to get from one input to one output. It is in the following format

(input,output) :  ( (relay slave, relay bit position, bit high "1" or low "0"), (...), (...), (...), (...) )

relay slave # comes from pcb layout and silkscreen, pin or bit position in register are counted 0 through 7 
-- ex: 00000100 -- postion 2 is set to high,

there are 5 relays per path, so 5 (slave#, pin/bit #, high/low) combinations per path, this is then organized and interpreted 
by a few functions in order to get each bit to the correct register. the functions allow this for multiple paths to be input at once.
'''

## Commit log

2022-09-08 Updated file names and Mcontrol file
    condensed code in Mcontrol and added a better short circuit protection implementation.
2022-09-19 Updated to V1.1
    A few minor changes were made most significantly the correction of some footprint errors (specifically on relays and the I2C controller resistors) which made assembly of the component impossible.
    [Bill of Materials-Multiplexor.xlsx, Multiplexor.PrjPcb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]
2022-12-05 Minor Updates following Testing
    Following receiving the board and testing minor changes to the FW have been made as well as some notes about the HW. Particularly about an EMI issues discovered.
    [MultiplexorControl.py, pathdict.py]
2023-02-22 Minor updates
    removed threading of timers
